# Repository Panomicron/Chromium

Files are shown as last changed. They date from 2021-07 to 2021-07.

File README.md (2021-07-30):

# Chromium
## The Panomicron Chromium is an open compact camera project
the guiding principle and main point of a film compact camera is in the name, **compact**, everything is done to keep the camera as small as possible, (with the manufacturing methods I have had access to). 

Currently the camera needs some components to be machined for rigidity and smooth operations sake. the rest is 3d printable with a FDM 3d printer.

Still working on full documentation.

# Known Issues
- [x] The battery cover is held closed with magnets and is not strong enough to counteract the contact springs, It has been redesigned to use a locking mechanism instead, it has not yet been printed and tested.
- [ ] The geartrain tends to jam on rewinds, the motor has a hard time overcoming internal friction in the film cansiter or on the final swinging gear (?) and will push the swing arm out - will be prototyped in POM to see if friction can be reduced - otherwise another sytem might need to be devised
- [ ] Still a lot of noise in the system, and functions can trigger on their own, more small capacitors need to be added in general 
- [ ] Counter EEPROM value sometimes resets mid roll, once this has been fixed the camera could potentially automatically prompt rewind, currently you know the roll is finished because the motors will stall.

# To be done

- [ ] full documentation

- [ ] Lightmeter
  - [ ] Auto Exposure
  - [ ] Shutter Priority
  - [ ] Complete A mode
  - [ ] Metering Modes?
 
- [ ] Menu & Modes
  - [ ] Sport Mode
  - [ ] Silent Mode (no advance until shutter button is released , à la Hexar RF
  - [ ] Multiple Exposure Mode

- [ ] Hotshoe, Flash Sync
  
- [ ] whole new 24x35mm variant of the camera, needs shutter to be flipped around as the motor would interfere in the frame, and would use a more aproriate lens, gear train would need to be modified, body widened.

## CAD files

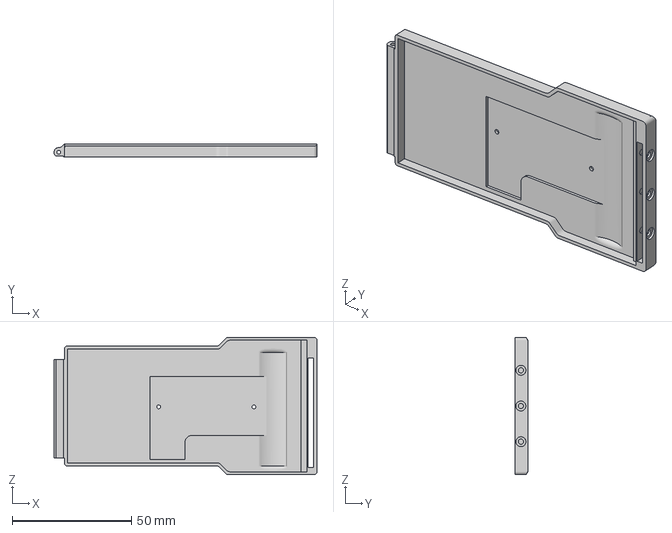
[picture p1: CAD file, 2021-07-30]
Chromium/Hardware/Back/back one piece.3mf
110.5 x 5.50 x 57.8 mm

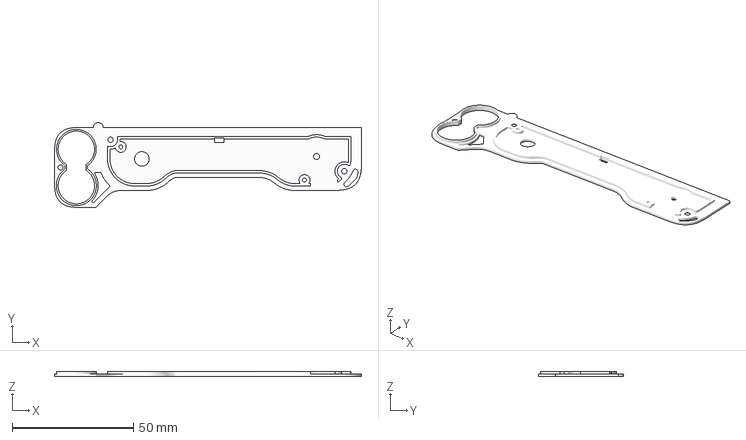
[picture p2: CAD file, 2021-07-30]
Chromium/Hardware/Body/3. bottom plate.3mf
126.5 x 35.0 x 2.00 mm

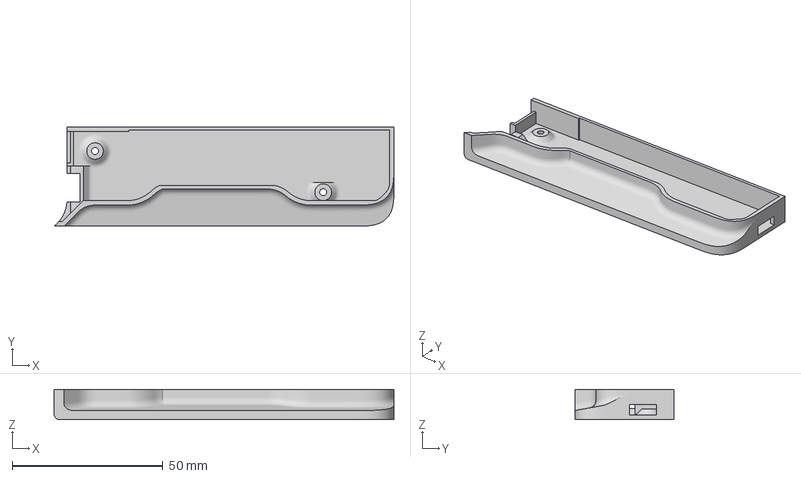
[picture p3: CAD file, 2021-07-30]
Chromium/Hardware/Body/bottom housing & cover 1-2/1.bottom housing.3mf
112.8 x 33.0 x 10.0 mm

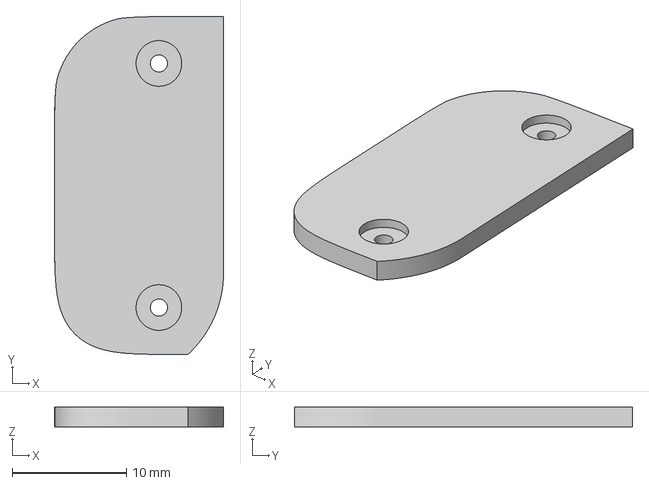
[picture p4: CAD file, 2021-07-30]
Chromium/Hardware/Body/bottom housing & cover 1-2/new/battery door top.3mf
14.8 x 29.6 x 1.75 mm

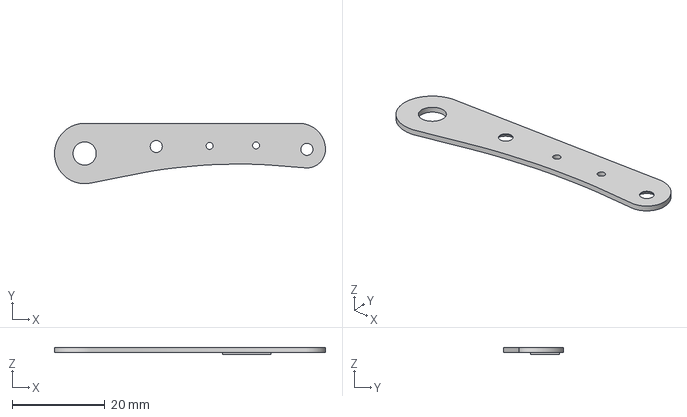
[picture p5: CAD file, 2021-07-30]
Chromium/Hardware/Body/geartrain/geartrain cover.3mf
58.4 x 13.0 x 1.45 mm

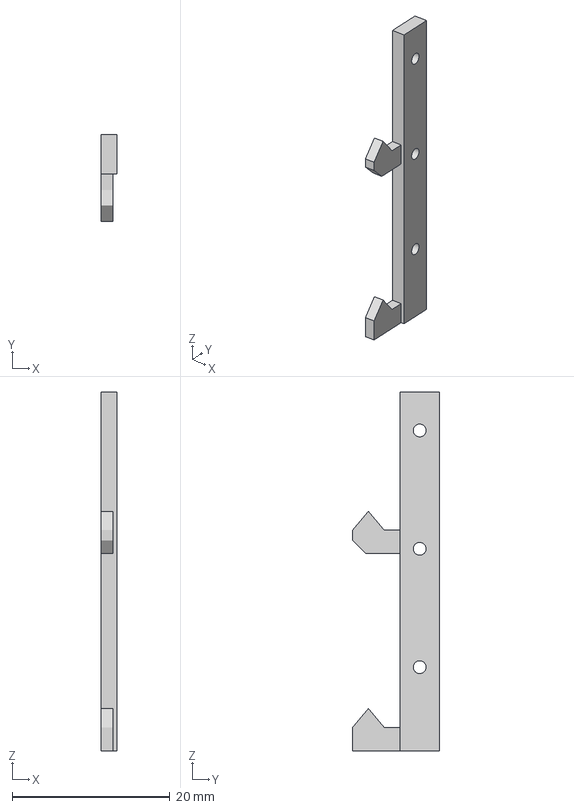
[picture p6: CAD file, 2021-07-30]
Chromium/Hardware/Back/back teeth.3mf
2.00 x 11.0 x 45.5 mm

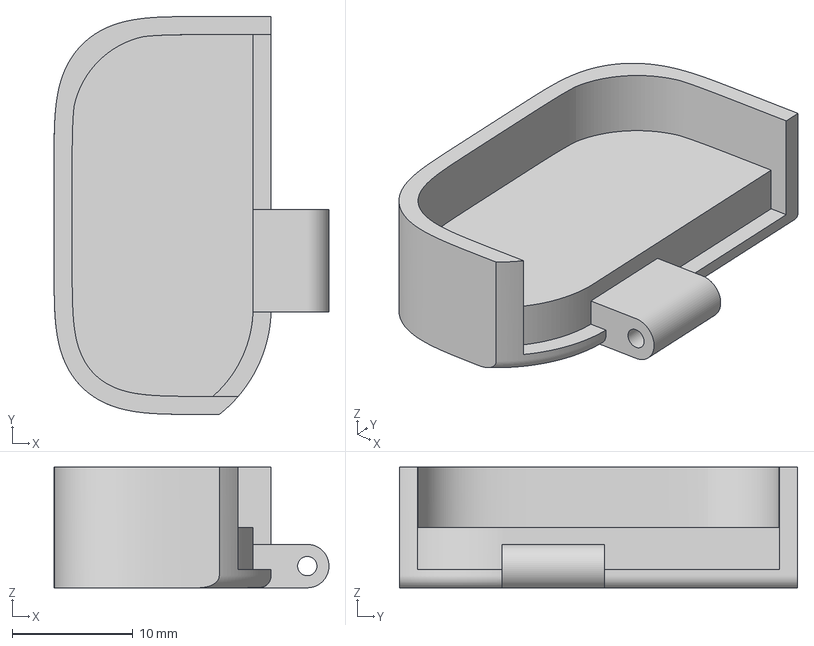
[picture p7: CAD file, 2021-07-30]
Chromium/Hardware/Body/bottom housing & cover 1-2/2. battery_cover.3mf
22.8 x 33.0 x 10.0 mm

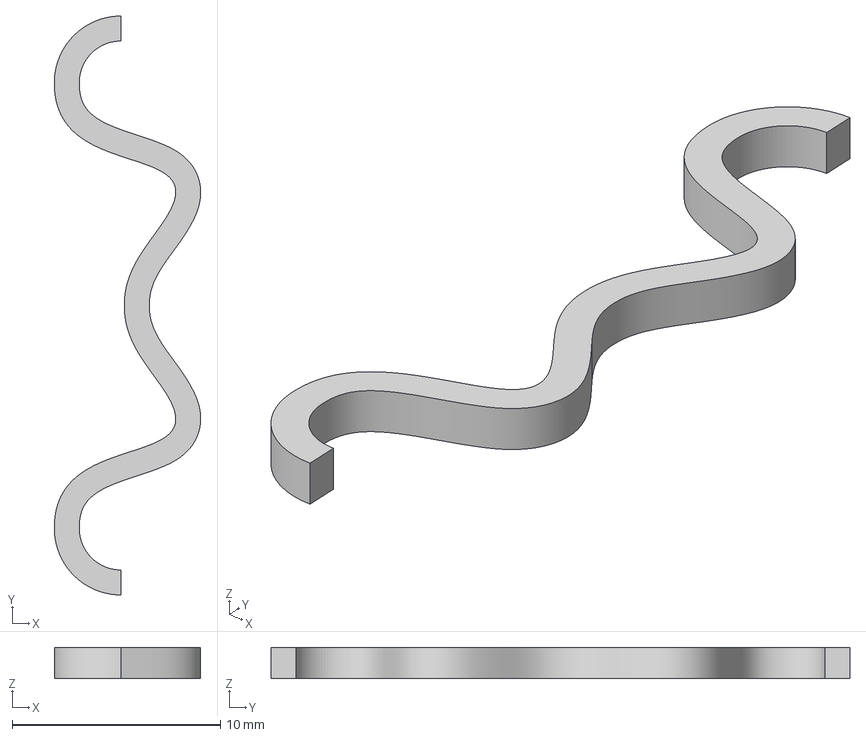
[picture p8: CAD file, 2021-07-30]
Chromium/Hardware/Body/bottom housing & cover 1-2/new/battery door spring.3mf
7.03 x 27.8 x 1.50 mm

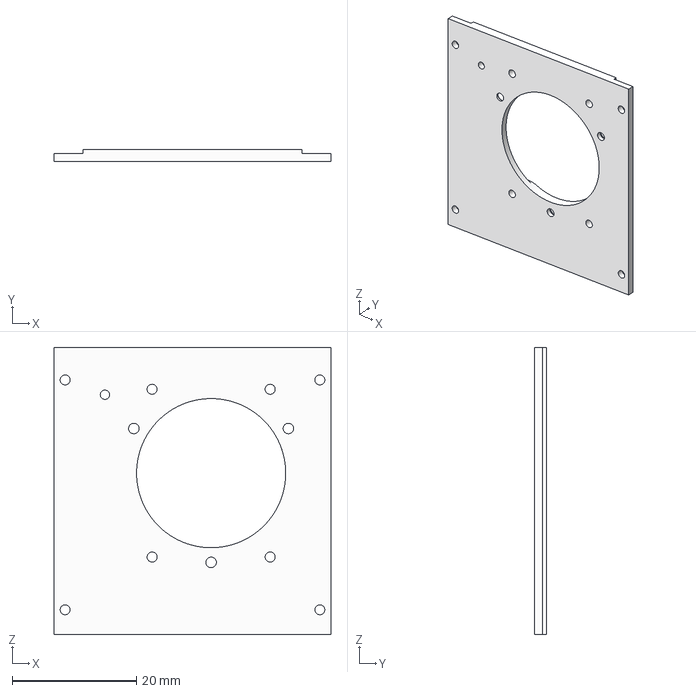
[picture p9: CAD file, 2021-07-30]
Chromium/Hardware/Body/front plate - 2mm.3mf
44.6 x 2.00 x 46.2 mm

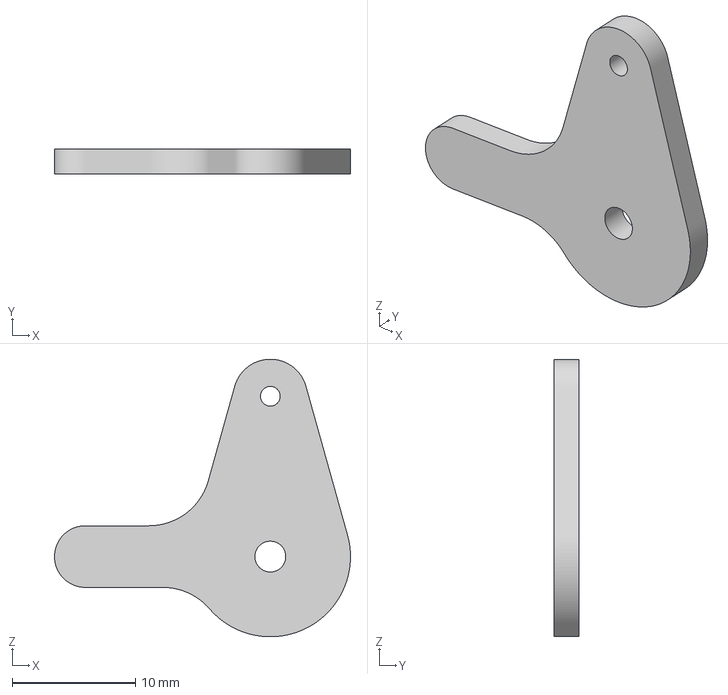
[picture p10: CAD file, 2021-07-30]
Chromium/Hardware/Body/geartrain/swing arm.3mf
24.0 x 2.00 x 22.5 mm

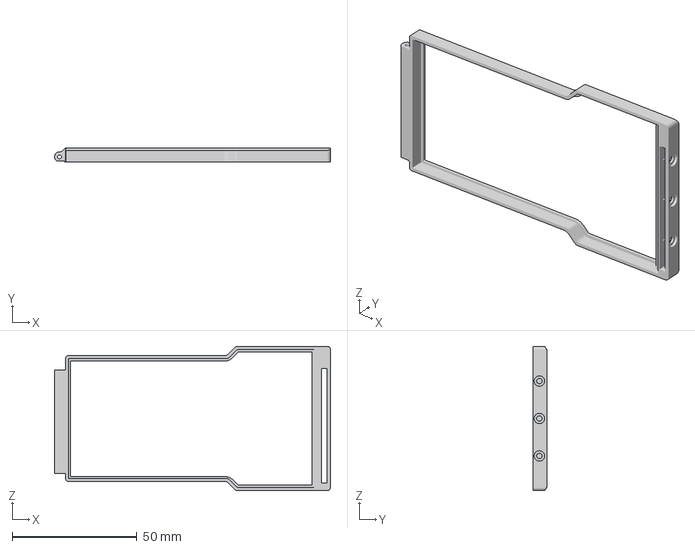
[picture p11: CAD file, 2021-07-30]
Chromium/Hardware/Back/back - frame.3mf
110.5 x 5.50 x 57.8 mm

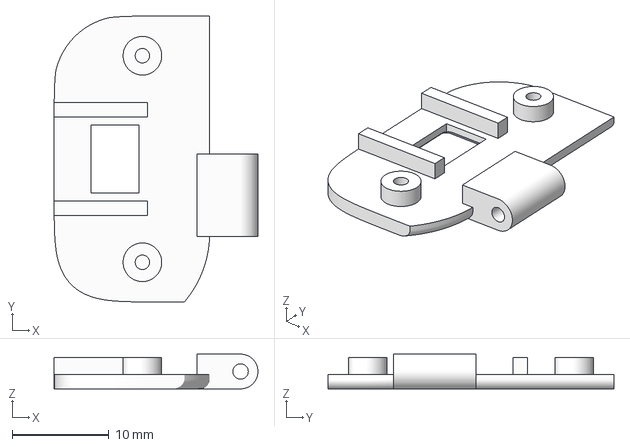
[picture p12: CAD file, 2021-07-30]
Chromium/Hardware/Body/bottom housing & cover 1-2/new/battery door bottom.3mf
21.1 x 29.6 x 3.60 mm

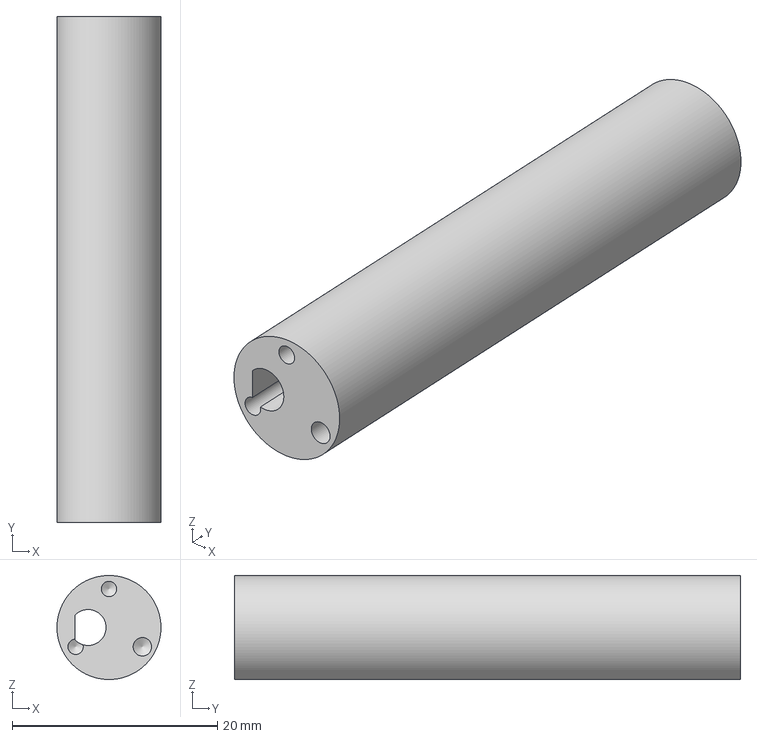
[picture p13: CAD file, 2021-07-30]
Chromium/Hardware/Body/geartrain/spool.3mf
10.1 x 49.2 x 10.1 mm

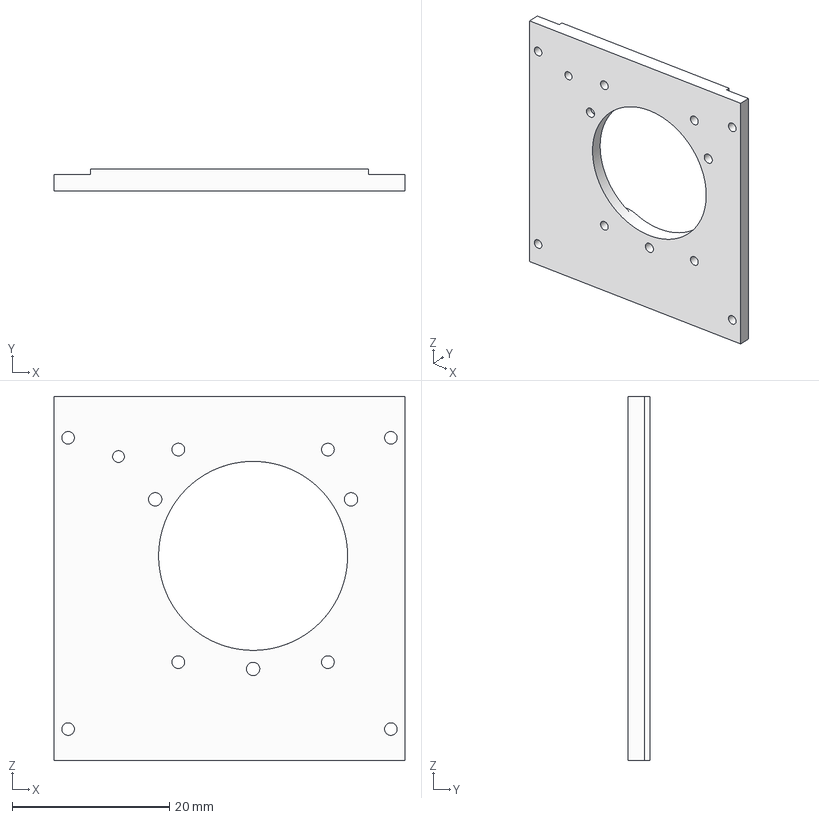
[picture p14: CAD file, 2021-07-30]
Chromium/Hardware/Body/thicker front plate.3mf
44.6 x 2.76 x 46.2 mm

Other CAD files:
Chromium/Hardware/Body/bottom housing & cover 1-2/new/bottom housing - new.3mf
Chromium/Hardware/Body/film door latch - lock.3mf
Chromium/Hardware/Body/geartrain/10 teeth.3mf
Chromium/Hardware/Body/bottom housing & cover 1-2/new/battery door latch.3mf
Chromium/Hardware/Body/0.03inch spacer.3mf
Chromium/Hardware/Body/4 body.3mf
Chromium/Hardware/Body/5. top housing spacer.3mf
Chromium/Hardware/Body/5. top housing.3mf
Chromium/Hardware/Body/6.top plate.3mf
Chromium/Hardware/Body/Interface Holder.3mf
Chromium/Hardware/Body/battery contact cover.3mf
Chromium/Hardware/Body/film door latch - baselpate.3mf
Chromium/Hardware/Body/film door latch - cover.3mf
Chromium/Hardware/Body/film gate.3mf
Chromium/Hardware/Body/geartrain/12 teeth.3mf
Chromium/Hardware/Body/geartrain/13 teeth.3mf
Chromium/Hardware/Body/geartrain/18 teeth.3mf
Chromium/Hardware/Body/geartrain/Canister gear -16 teeth.3mf
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

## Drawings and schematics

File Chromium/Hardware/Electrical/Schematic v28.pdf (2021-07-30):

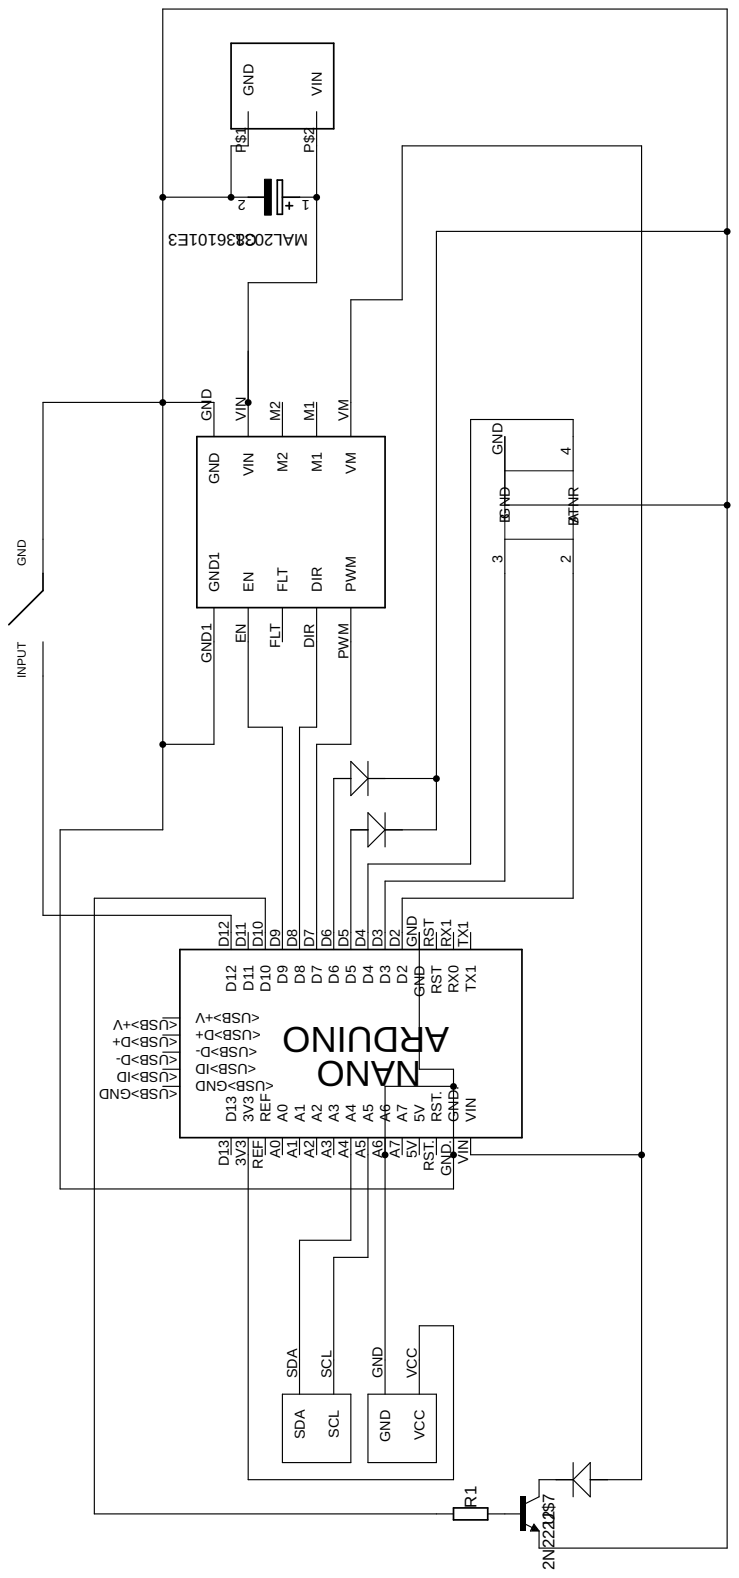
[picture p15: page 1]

3V3 D13 D13 DNG>BSU< DNG>BSU<

5V RST. RST. GND. GND. A5 A5 A4 A4 A3 A3 A2 A2 A1 A1 A0 A0 A6 A6 A7 A7

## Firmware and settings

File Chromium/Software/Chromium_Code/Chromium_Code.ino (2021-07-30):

#include <Rotary.h> //https://github.com/buxtronix/arduino/tree/master/libraries/Rotary
#include <SPI.h>
#include <EEPROM.h>
#include <Wire.h>
#include <Adafruit_GFX.h>
#include <Adafruit_SSD1306.h>


#define SCREEN_WIDTH 128 // OLED display width, in pixels
#define SCREEN_HEIGHT 32 // OLED display height, in pixels

#define OLED_RESET     -1 // Reset pin # (or -1 if sharing Arduino reset pin)
#define SCREEN_ADDRESS 0x3C ///< See datasheet for Address; 0x3D for 128x64, 0x3C for 128x32
Adafruit_SSD1306 display(SCREEN_WIDTH, SCREEN_HEIGHT, &Wire, OLED_RESET);
//Adafruit_SSD1306 display(OLED_RESET);

int addr = 0;

const int counterRead = 5; // IR sensor of the counter
const int counterLed = 6; // IR LED of the counter

const int shutterRead = 12; // INPUT PULL-UP shutter button, when it gets pulled down the shutter is fired.

const int motorPWM = 7; // motors pins
const int motorDir = 8;
const int motorEnable = 9;

const int firePin = 10; // connected to the base of a NPN transistor, when put to high the shutter opens

Rotary rotary = Rotary(2, 3); //set up for the rotary encoder library 

const int encoderSwitchPin = 4; //push button switch

const float SHUTTER_TABLE[] = {30.0, 15.0, 8.0, 4.0, 2.0, 1.0, 2.0, 4.0, 8.0, 15.0, 30.0, 60.0, 125.0, 250.0, 500.0};

int counter = 10;
float invShutterDisplay;
float shutterDisplay = 0;
int lastCounter = 10;

int shutterSpeed = 17;

unsigned long onTime = 0;

int rewindState = 0;
int lastRewindState = 1;

int counter_incr = 0;
int frame = EEPROM.read(0);


void setup() {

  delay(2000);
  Serial.begin (9600);

  //SSD1306_SWITCHCAPVCC = generate display voltage from 3.3V internally
  display.begin(SSD1306_SWITCHCAPVCC, SCREEN_ADDRESS);
  display.clearDisplay();
  display.display();
  frameDisplay();
  shutterSet();


  pinMode(A6, OUTPUT);
  digitalWrite(A6, LOW); //A6 is used as GND for the display.

  pinMode(counterRead, INPUT_PULLUP);
  pinMode(counterLed, OUTPUT);

  pinMode(shutterRead, INPUT_PULLUP);
  pinMode(firePin, OUTPUT);

  pinMode(encoderSwitchPin, INPUT);
  digitalWrite(encoderSwitchPin, HIGH); //turn pullup resistor on

  pinMode(motorPWM, OUTPUT);
  pinMode(motorEnable, OUTPUT);
  pinMode(motorDir, OUTPUT);
  
  digitalWrite(motorPWM, LOW);
  digitalWrite(motorEnable, LOW);
  digitalWrite(motorDir, LOW);


}

void loop() {
  // put your main code here, to run repeatedly:
  if (counter != lastCounter) {
    shutterSet();
  }

  if (digitalRead(shutterRead) == LOW) {            // checks if shutter button is pressed, if yes runs shoot and then advance

    shoot();                                        // triggers the shutter
    delay(500);                                     // delay
    advance();                                      // advances the film to the next frame

  }

  rewindState = digitalRead(encoderSwitchPin);

  if (rewindState == 0 && rewindState != lastRewindState) { //checks whether the button has been pressed, and whether is has changed since last time it checked
    rewindTimer();
  }
  lastRewindState = rewindState;

  if (onTime > 0 && millis() - onTime > 1500){   // checks that the button has be pressed for 1.5s or longer 
    rewindroll();                                // rewinds roll, sets timer and frame count to 0
    onTime = 0;
    frame = 0;
    EEPROM.write(addr, frame);
  }

  else {
    // button is not being pushed.

  }


}

void rewindTimer() {

  onTime = millis(); // starts a timer to check that you're not pressing it by mistake

}

void rotate() {                                               // rotary encoder counter
  unsigned char result = rotary.process();
  if (result == DIR_CW) {
    counter++;
    //    Serial.println(counter);
  } else if (result == DIR_CCW) {
    counter--;
    //    Serial.println(counter);
  }

}


void shoot() {                                              

  digitalWrite(firePin, HIGH);                                    //opens the shutter
  delay(shutterSpeed);                                            // delays the duration of the shutter speed
  digitalWrite(firePin, LOW);                                     // closes the shutter

}

void led_Detect() {                                               //frame counter incrementing
  counter_incr++;
  // Serial.println("detect");
  //Serial.println(counter_incr);

}

void advance() {


  int IRState = 0;                                            // current state of the IR sensor
  int lastIRState = 0;                                        // last state of the IR sensor



  digitalWrite(counterLed, HIGH);                           //turns the IR LED in the back on
  digitalWrite(motorPWM, HIGH);                             // turns on motor outputs
  digitalWrite(motorEnable, LOW);
  digitalWrite(motorDir, HIGH);


  while (counter_incr <= 8) {// check if the frame has been fully advanced or not, if not then continue winding

    IRState = digitalRead(counterRead);


    
    if (IRState != lastIRState) {                                                   // compare the buttonState to its previous state
                                                                                    // if the state has changed, increment the counter
      if (IRState == LOW) {
                                                                                    // if the current state is LOW then the IR sensor was activated:
        counter_incr++;
      }
      else {
                                                                                   // if the current state is HIGH then the IR Sensor is not activated, so we can ignore :
      }
                                                                                   // Delay a little bit to avoid bouncing
      delay(100);
    }
                                                                                   // save the current state as the last state, for next time through the loop
    lastIRState = IRState;

  }
                                                                                   //count_incr over 6, stop winding and count the frame.
  digitalWrite(motorPWM, LOW);
  digitalWrite(motorEnable, LOW);
  digitalWrite(motorDir, LOW);
  digitalWrite(counterLed, LOW);
  counter_incr = 0;
  frame++;

  //Serial.println("frame:");
  //Serial.print(frame);

  EEPROM.write(addr, frame);
  frameDisplay();

}

void rewindroll () {


  while (digitalRead(encoderSwitchPin) == 0) {

    digitalWrite(motorPWM, HIGH);
    digitalWrite(motorEnable, LOW);
    digitalWrite(motorDir, LOW);
    delay(300);                                                                   // delay seens to help avoid noise
  }
 
  delay(300);
  digitalWrite(motorPWM, LOW);
  digitalWrite(motorEnable, LOW);
  digitalWrite(motorDir, LOW);


}


void frameDisplay(void) {

  display.fillRect(0, 0, 40, 14, SSD1306_BLACK); // clears the frame section of the display without impacting the rest
  display.display();
  delay(1);

  display.setTextSize(2);             //  2:1 pixel scale
  display.setTextColor(SSD1306_WHITE);        // Draw white text
  display.setCursor(0, 0);            // Start at top-left corner
  if (frame <= 9) {                             // if the frame is a single digit number a 0 needs to be printed before the frame value.
    display.print(0);
    display.print(frame);

  }
  else {
    display.print(frame);                       // if it's double digits then you can just print the number
  }

  display.fillRect(27, 0, 4, 2, SSD1306_WHITE);          // draws a little canister
  display.fillRect(25, 2, 8, 12,  SSD1306_WHITE);
  display.drawRect(33, 3, 3, 10, SSD1306_WHITE);



  display.display();
  delay(250); // updates the display
  return;
}

void shutterSet(void) {

  display.fillRect(50, 0, 40, 14, SSD1306_BLACK);           //clears the shutterspeed side of the display
  display.display();


  display.setCursor(50, 0);             // Cursor at x50 y0
  display.setTextSize(2);             //  2:1 pixel scale
  display.setTextColor(SSD1306_WHITE);        // Draw white text


  counter = constrain (counter, 0, 14);                   //limit the counter the the number of values in the shutter table array

  shutterDisplay = SHUTTER_TABLE[counter];
  invShutterDisplay = 1 / shutterDisplay;                 // invShutterDisplay is the reciprocal of the shutterDisplay, this gives the needed shutter speed as a float


  if (counter >= 6) {                                       // if the counter is in the fraction section of the shutter speed array
    display.print(shutterDisplay, 0);

    shutterSpeed = (int)(invShutterDisplay * 1000);   // invShutterDisplay is multiplied by a thousand and made an integer to be used as a delay value



  }
  else {
    display.print(shutterDisplay, 0);
    display.print(F("s"));
    shutterSpeed = (int)(shutterDisplay * 1000);  

  }

  display.display();
  lastCounter = counter;

  // updates the display


}
